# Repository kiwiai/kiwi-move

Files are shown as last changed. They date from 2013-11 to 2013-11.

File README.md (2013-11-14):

The Kiwi Move

These are the hardware design files for the Kiwi Move, developed by Kiwi Wearable Technologies Ltd.

These files have been made available online through a Creative Commons Attribution-ShareAlike 3.0 license. You are welcome to distribute, remix, and use these files for commercial purposes. If you do so, please attribute the original design to Kiwi Wearable Technologies Ltd. and all parties involved in developing to this point including Spark Devices in your schematic. All derivative works must be published under the same or a similar license. The design is built off of a number of open source projects including the Spark Core (https://github.com/spark/core)

Development of the Kiwi Move began in May 2013 in Toronto, Canada after the founding team participated in a local computer competition. The Kiwi Platform began its development in the spring of 2011 built on the basis of a number of sensorial and data acquisition devices. This initial release of hardware design files are for those in the GitHub and open-source community to make the most of for wearable technology devices.

What Hardware Design Files are Included:

EAGLE — Schematic and board files for the Kiwi Move. 

GERBER Files - For making your own runs of the Kiwi Move.

Pin Mapping — Detailed pin mapping of the Kiwi Move and STM32, providing information about which pins are mapped to which peripherals.

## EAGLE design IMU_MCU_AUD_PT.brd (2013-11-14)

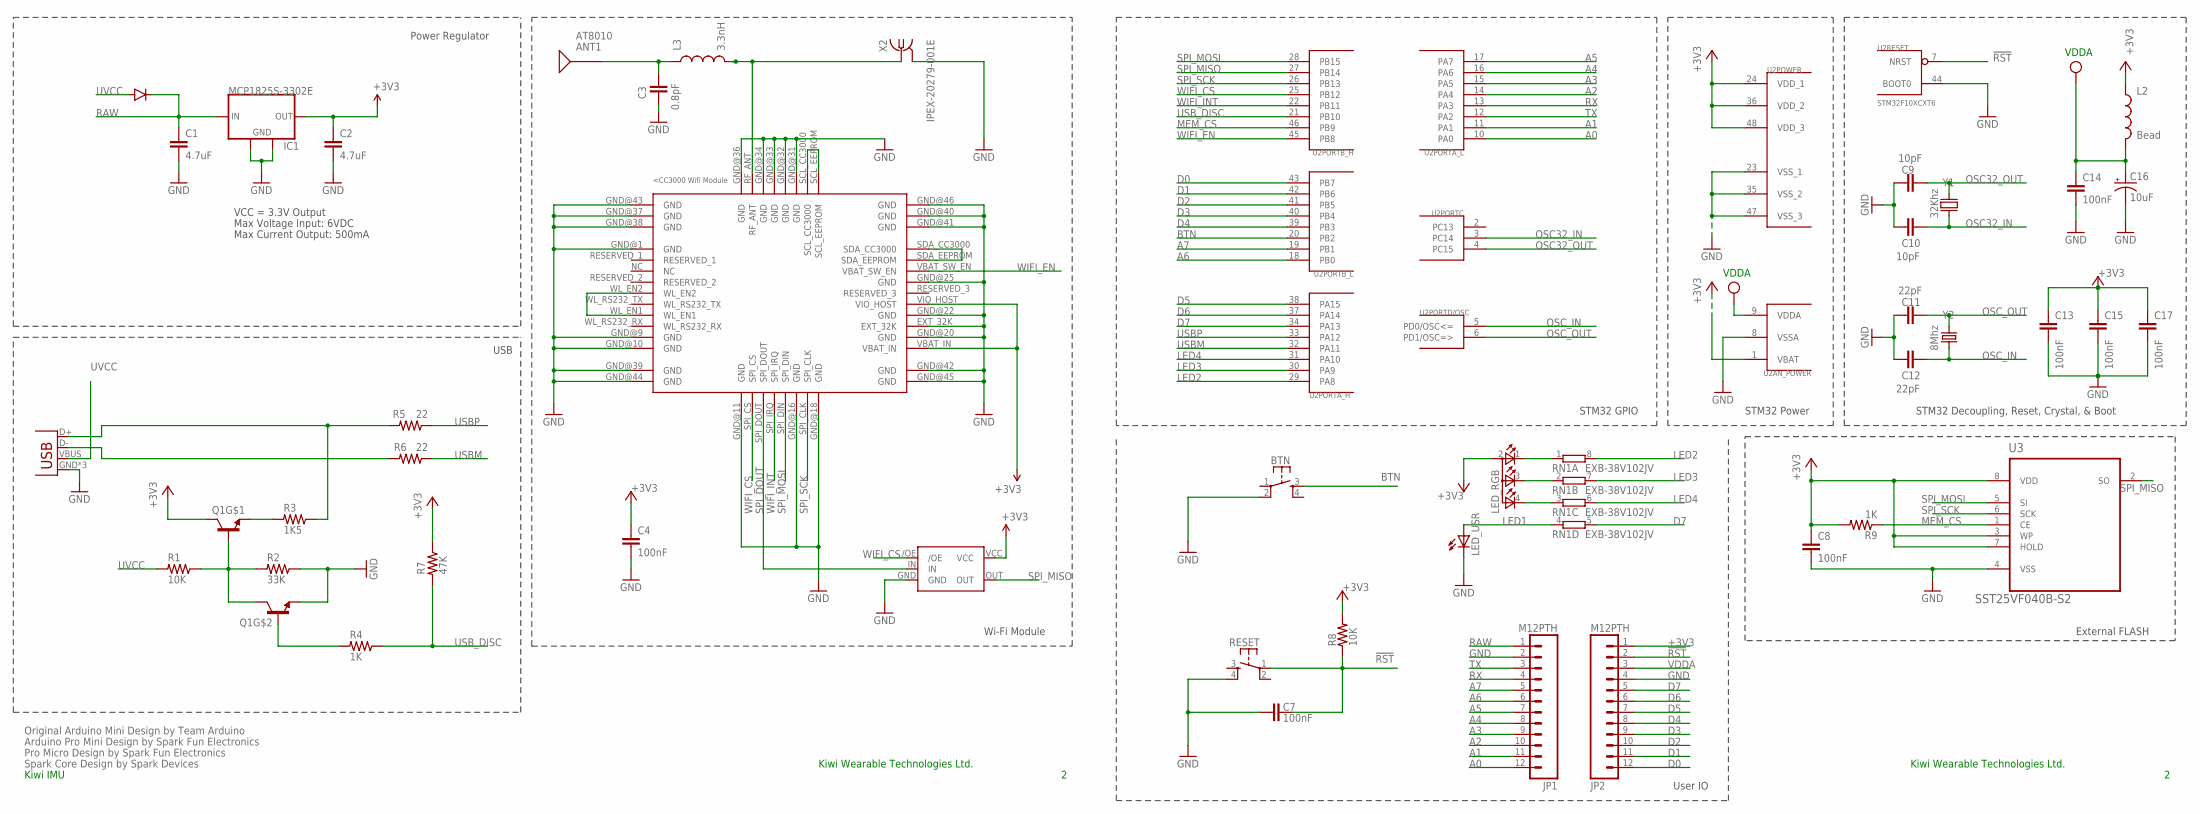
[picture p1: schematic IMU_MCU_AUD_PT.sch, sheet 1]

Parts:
ANT1: AT8010
B1: NL17SZ125SOT553; SOT-553
BTN: KMR211GLFS; TACTILE_SWITCH_SMD
C1, C2: 4.7uF; C0603
C3: 0.8pF; C0603
C4, C7, C8, C13, C14, C15, C17: 100nF; C0603
C9, C10: 10pF; C0603
C11, C12: 22pF; C0603
C16: 10uF; EIA3216
IC1: MCP1825S-3302E; SOT223
JP1, JP2: M12PTH; 1X12-SMALL-PADS
L2: Bead; 0603
L3: 3.3nH; 0603
LED_RGB: TOPLED-3PLCC; P-LCC-4-3
LED_USR: LED0603; LED-0603
Q1: MMDT3904; SOT363
R1, R8: 10K; R0603
R2: 33K; R0603
R3: 1K5; R0603
R4, R9: 1K; R0603
R5, R6: 22; R0603
R7: 47K; R0603
RESET: KMR211GLFS; TACTILE_SWITCH_SMD
RN1: EXB-38V102JV; EXB38V
U1: CC3000
U2: STM32F10XCXT6; TQFP48
U3: SST25VF040B-S2; SOIC127P790X216-8N
U$3: DIODE; DIODE-DO-220AA(SMP)
X1: USB-MICROB; USB-MICROB-SLOT-HOLE
X2: IPEX-20279-001E
Y1: 32Khz; FC135
Y2: 8Mhz; CRYSTAL-SMD-5X3

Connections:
3.3V: B1.VCC
!RST: C7.2, JP2.2, R8.1, RESET.1, U2.7 (NRST)
+3V3: C2.1, C4.1, C8.1, C13.1, C15.1, C17.1, IC1.3 (OUT), JP2.1, L2.1, LED_RGB.2 (A2), Q1.3 (C), R7.1, R8.2, R9.2, U1.VBAT_IN, U1.VIO_HOST, U2.1 (VBAT), U2.24 (VDD_1), U2.36 (VDD_2), U2.48 (VDD_3), U3.3 (WP), U3.7 (HOLD), U3.8 (VDD); also elsewhere on the board
A0: JP1.12, U2.10 (PA0); also elsewhere on the board
A1: JP1.11, U2.11 (PA1); also elsewhere on the board
A2: JP1.10, U2.14 (PA4)
A3: JP1.9, U2.15 (PA5)
A4: JP1.8, U2.16 (PA6)
A5: JP1.7, U2.17 (PA7)
A6: JP1.6, U2.18 (PB0); also elsewhere on the board
A7: JP1.5, U2.19 (PB1)
BTN: BTN.3, U2.20 (PB2)
D0: JP2.12, U2.43 (PB7); also elsewhere on the board
D1: JP2.11, U2.42 (PB6); also elsewhere on the board
D2: JP2.10, U2.41 (PB5)
D3: JP2.9, U2.40 (PB4); also elsewhere on the board
D4: JP2.8, U2.39 (PB3); also elsewhere on the board
D5: JP2.7, U2.38 (PA15); also elsewhere on the board
D6: JP2.6, U2.37 (PA14); also elsewhere on the board
D7: JP2.5, RN1.5 (2), U2.34 (PA13)
GND: B1.GND, BTN.2, C1.2, C2.2, C3.1, C4.2, C7.1, C8.2, C9.2, C10.2, C11.2, C12.2, C13.2, C14.2, C15.2, C16.C (-), C17.2, IC1.2 (GND), IC1.4 (GND), JP1.2, JP2.4, LED_USR.C, Q1.1 (E), R2.1, RESET.4, U1.EXT_32K, U1.GND@1 (GND), U1.GND@9 (GND), U1.GND@10 (GND), U1.GND@11 (GND), U1.GND@16 (GND), U1.GND@18 (GND), U1.GND@20 (GND), U1.GND@22 (GND), U1.GND@25 (GND), U1.GND@31 (GND), U1.GND@32 (GND), U1.GND@33 (GND), U1.GND@34 (GND), U1.GND@36 (GND), U1.GND@37 (GND), U1.GND@38 (GND), U1.GND@39 (GND), U1.GND@40 (GND), U1.GND@41 (GND), U1.GND@42 (GND), U1.GND@43 (GND), U1.GND@44 (GND), U1.GND@45 (GND), U1.GND@46 (GND), U2.8 (VSSA), U2.23 (VSS_1), U2.35 (VSS_2), U2.44 (BOOT0), U2.47 (VSS_3), U3.4 (VSS), X1.GND, X1.MT1 (GND), X1.MT2 (GND), X2.2@1 (GND), X2.2@2 (GND); also elsewhere on the board
LED1: LED_USR.A, RN1.4 (1)
LED2: RN1.8 (2), U2.29 (PA8)
LED3: RN1.7 (2), U2.30 (PA9)
LED4: RN1.6 (2), U2.31 (PA10)
MEM_CS: R9.1, U2.46 (PB9), U3.1 (CE)
unnamed: R3.1, R5.2, X1.D+
unnamed: ANT1.SIG, C3.2, L3.1
unnamed: L3.2, U1.RF_ANT, X2.1
unnamed: R6.2, X1.D-
unnamed: U1.SCL_CC3000, U1.SCL_EEPROM
unnamed: Q1.2 (B), R4.2
unnamed: U1.WL_EN1, U1.WL_EN2
unnamed: LED_RGB.1 (CRED), RN1.1
unnamed: LED_RGB.3 (CBLUE), RN1.2 (1)
unnamed: Q1.5 (B), Q1.6 (C), R1.1, R2.2
unnamed: LED_RGB.4 (CGREEN), RN1.3 (1)
unnamed: U1.SDA_CC3000, U1.SDA_EEPROM
unnamed: Q1.4 (E), R3.2
OSC32_IN: C10.1, U2.3 (PC14), Y1.X1 (1)
OSC32_OUT: C9.1, U2.4 (PC15), Y1.X2 (2)
OSC_IN: C12.1, U2.5 (PD0/OSC<=), Y2.1
OSC_OUT: C11.1, U2.6 (PD1/OSC=>), Y2.3 (2)
RAW: C1.1, IC1.1 (IN), JP1.1, U$3.CATHODE
RX: JP1.4, U2.13 (PA3)
SPI_DOUT: B1.IN, U1.SPI_DOUT
SPI_MISO: B1.OUT, U2.27 (PB14), U3.2 (SO)
SPI_MOSI: U1.SPI_DIN, U2.28 (PB15), U3.5 (SI)
SPI_SCK: U1.SPI_CLK, U2.26 (PB13), U3.6 (SCK)
TX: JP1.3, U2.12 (PA2)
USBM: R6.1, U2.32 (PA11)
USBP: R5.1, U2.33 (PA12)
USB_DISC: R4.1, R7.2, U2.21 (PB10)
UVCC: R1.2, U$3.ANODE, X1.VBUS
VDDA: C14.1, C16.A (+), JP2.3, L2.2, U2.9 (VDDA)
WIFI_CS: B1./OE, U1.SPI_CS, U2.25 (PB12)
WIFI_EN: U1.VBAT_SW_EN, U2.45 (PB8)
WIFI_INT: U1.SPI_IRQ, U2.22 (PB11)

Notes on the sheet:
Original Arduino Mini Design by Team Arduino
Arduino Pro Mini Design by Spark Fun Electronics
Max Voltage Input: 6VDC
Max Current Output: 500mA
Power Regulator
VCC = 3.3V Output
Pro Micro Design by Spark Fun Electronics
Spark Core Design by Spark Devices
STM32 Decoupling, Reset, Crystal, & Boot
STM32 GPIO
STM32 Power
External FLASH
User IO
USB
Wi-Fi Module
VDDA
Kiwi IMU
Kiwi Wearable Technologies Ltd.

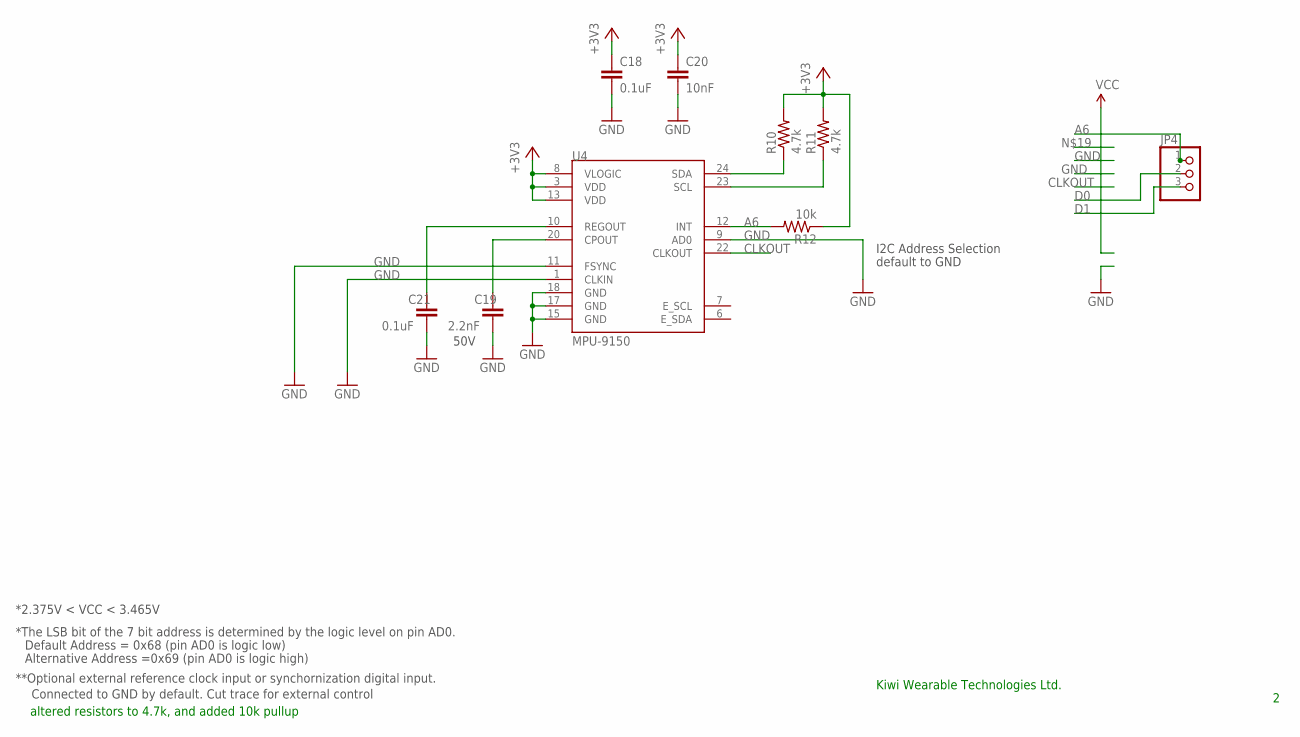
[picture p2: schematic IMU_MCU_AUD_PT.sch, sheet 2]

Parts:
C18, C21: 0.1uF; 0402-CAP
C19: 2.2nF; 0402-CAP
C20: 10nF; 0402-CAP
JP4: PINHD-1X3; 1X03
R10, R11: 4.7k; 0402-RES
R12: 10k; 0402-RES
U4: MPU-9150; QFN-24-NP

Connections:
+3V3: C18.1, C20.1, R10.2, R11.2, R12.1, U4.3 (VDD), U4.8 (VLOGIC), U4.13 (VDD); also elsewhere on the board
A6: JP4.1, R12.2, U4.12 (INT); also elsewhere on the board
CLKOUT: U4.22 (CLKOUT)
D0: JP4.2, R10.1, U4.24 (SDA); also elsewhere on the board
D1: JP4.3, R11.1, U4.23 (SCL); also elsewhere on the board
GND: C18.2, C19.2, C20.2, C21.2, U4.1 (CLKIN), U4.9 (AD0), U4.11 (FSYNC), U4.15 (GND), U4.17 (GND), U4.18 (GND); also elsewhere on the board
unnamed: C19.1, U4.20 (CPOUT)
unnamed: C21.1, U4.10 (REGOUT)

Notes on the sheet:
50V
I2C Address Selection
**Optional external reference clock input or synchornization digital input.
Connected to GND by default. Cut trace for external control
Default Address = 0x68 (pin AD0 is logic low)
Alternative Address =0x69 (pin AD0 is logic high)
*The LSB bit of the 7 bit address is determined by the logic level on pin AD0.
default to GND
*2.375V < VCC < 3.465V
altered resistors to 4.7k, and added 10k pullup
Kiwi Wearable Technologies Ltd.

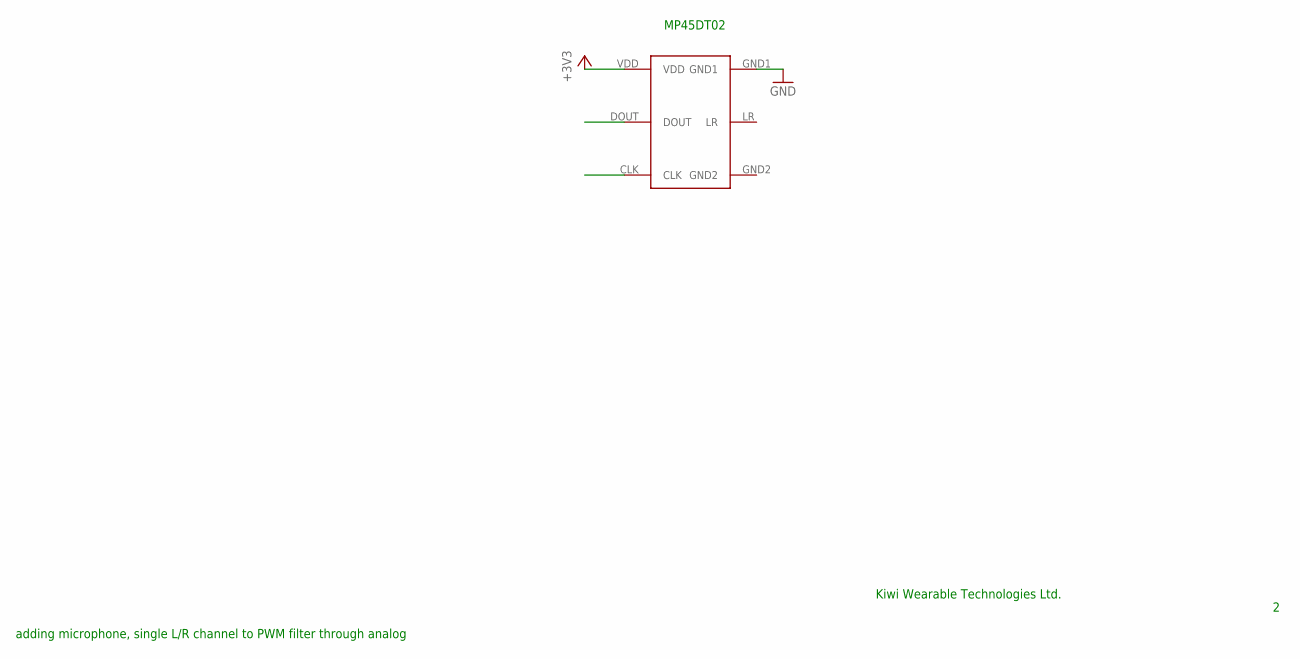
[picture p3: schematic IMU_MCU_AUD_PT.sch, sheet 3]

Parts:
M1: MP45DT02; HLGA

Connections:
+3V3: M1.VDD; also elsewhere on the board
A0: M1.CLK; also elsewhere on the board
A1: M1.DOUT; also elsewhere on the board
GND: M1.GND1; also elsewhere on the board

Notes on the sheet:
Kiwi Wearable Technologies Ltd.
MP45DT02
adding microphone, single L/R channel to PWM filter through analog

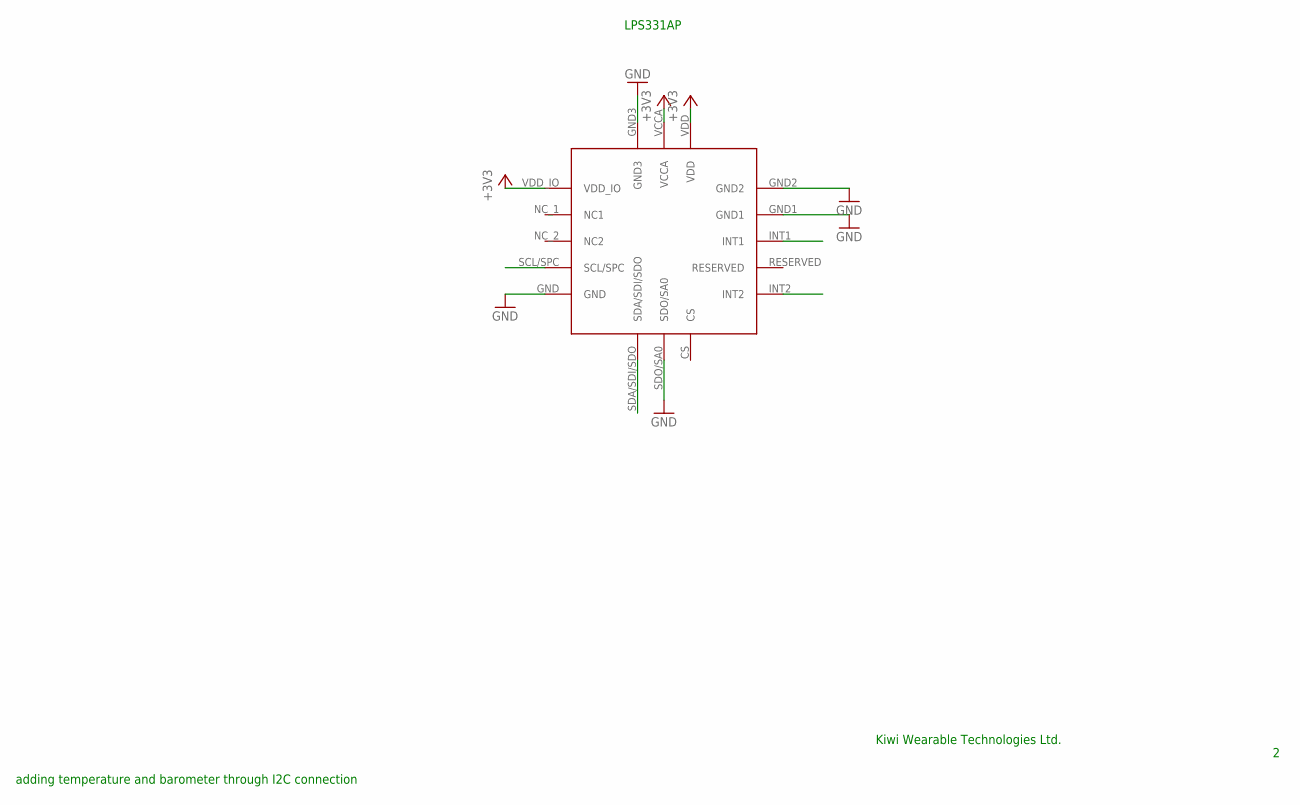
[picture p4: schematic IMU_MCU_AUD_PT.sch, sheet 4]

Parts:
P1: LPS331AP; HCLGA

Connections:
+3V3: P1.VCCA, P1.VDD, P1.VDD_IO; also elsewhere on the board
D3: P1.INT1; also elsewhere on the board
D4: P1.INT2; also elsewhere on the board
D5: P1.SCL/SPC; also elsewhere on the board
D6: P1.SDA/SDI/SDO; also elsewhere on the board
GND: P1.GND, P1.GND1, P1.GND2, P1.GND3, P1.SDO/SA0; also elsewhere on the board

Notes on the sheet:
Kiwi Wearable Technologies Ltd.
LPS331AP
adding temperature and barometer through I2C connection

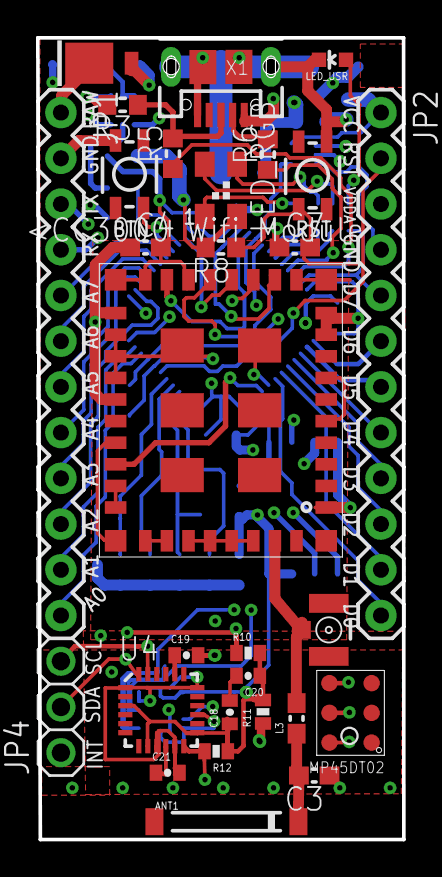
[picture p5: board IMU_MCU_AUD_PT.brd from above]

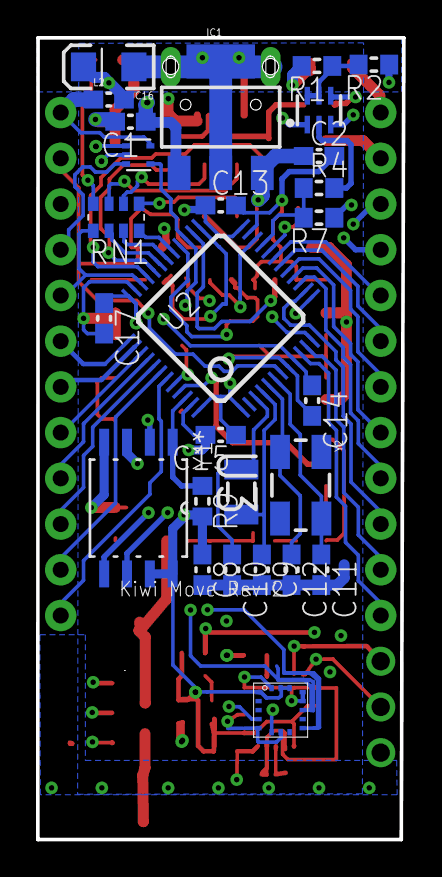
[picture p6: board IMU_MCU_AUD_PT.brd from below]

Board: 4 copper layers, 20.3 x 44.5 mm, 56 parts (27 on the bottom side), 59 nets.

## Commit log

2013-11-14 Get your move on with opensource!
    [IMU_MCU_AUD_PT.brd, IMU_MCU_AUD_PT.sch, kiwi-pin-mapping.xlsx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]
2013-11-14 fixing boarding and schematic layout
    [IMU_MCU_AUD_PT.brd, IMU_MCU_AUD_PT.sch]

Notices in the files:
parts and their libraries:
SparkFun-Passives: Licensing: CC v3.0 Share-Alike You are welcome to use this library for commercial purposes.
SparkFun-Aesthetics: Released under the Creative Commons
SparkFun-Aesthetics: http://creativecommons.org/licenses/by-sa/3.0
